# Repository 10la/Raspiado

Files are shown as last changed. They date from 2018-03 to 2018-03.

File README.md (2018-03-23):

## Raspiado

A USB hub that fits in the space and footprint of the existing Raspberry Pi.  Compatible with the RPi B, RPi B+, and RPi 2.

Power your Pi, add USB ports, and look great doing it!

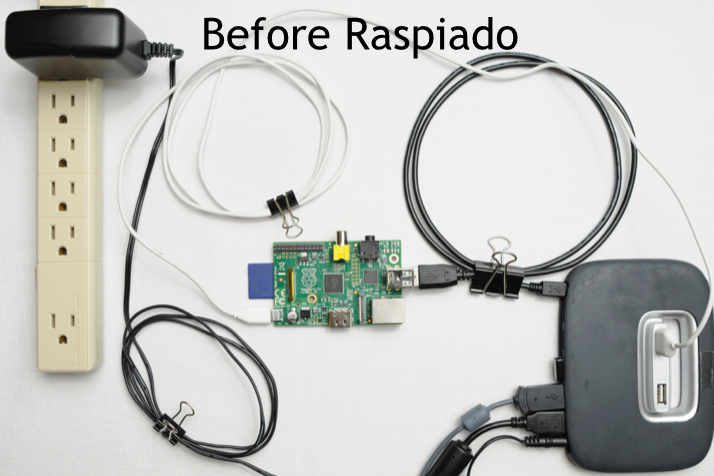
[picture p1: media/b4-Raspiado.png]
Before Rapiado


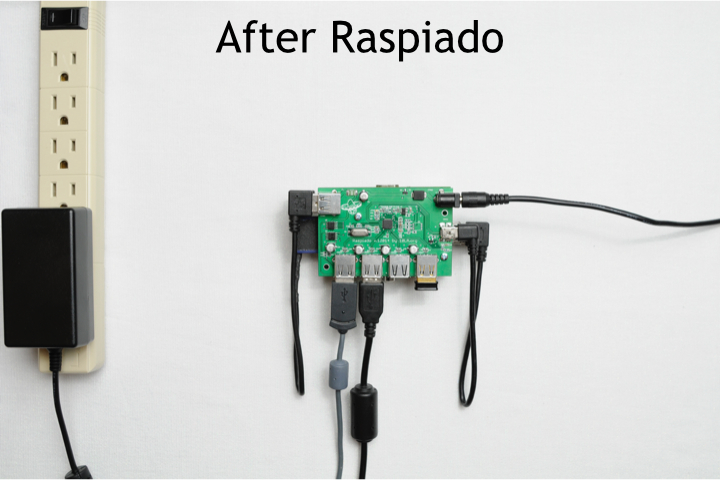
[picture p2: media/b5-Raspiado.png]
After Rapiado


******************
### File Descriptions
[4PxU_RPISB Specification.docx](https://github.com/10la/Raspiado/blob/master/4PxU_RPISB%20Specification.docx) is the hardware specification document created by Mindlab Tech for Raspiado.  It represents a formalized document that governs what functions and requirements Raspiado needed and how those things would be achieved.

[PCB Design Files](https://github.com/10la/Raspiado/tree/master/PCB%20Design%20Files) are the EAGLE files for the Raspiado board.

It includes 2 folders- the main design files are in [4PxU_RPi Rev B 18July2014](https://github.com/10la/Raspiado/tree/master/PCB%20Design%20Files/4PxU_RPi%20Rev%20B%2018July2014).  I had a small issue with the board logo and the resulting change are stored in [2014-10-3 new logo](https://github.com/10la/Raspiado/tree/master/PCB%20Design%20Files/2014-10-3%20new%20logo)

When I went to production with Raspiado, I required a few crossreferenced components in order to function with the inventory items that my PCB manufacturer preferred.  You can find those in the [BOM_Crossreferences](https://github.com/10la/Raspiado/blob/master/PCB%20Design%20Files/BOM_Raspiado_V1P4_crossreferences.xlsx) spreadsheet.

******************
### Kickstarter

Raspiado would have never seen the light of day with it's attractive, intelligent, and supportive backers.
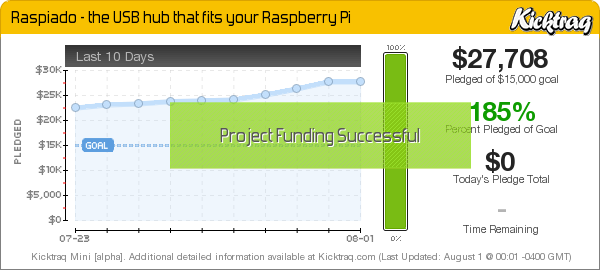
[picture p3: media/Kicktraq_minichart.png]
Kicktraq Stats


When I started the project, I never knew that I'd be able to create something that would be appreciated by people all over the world.
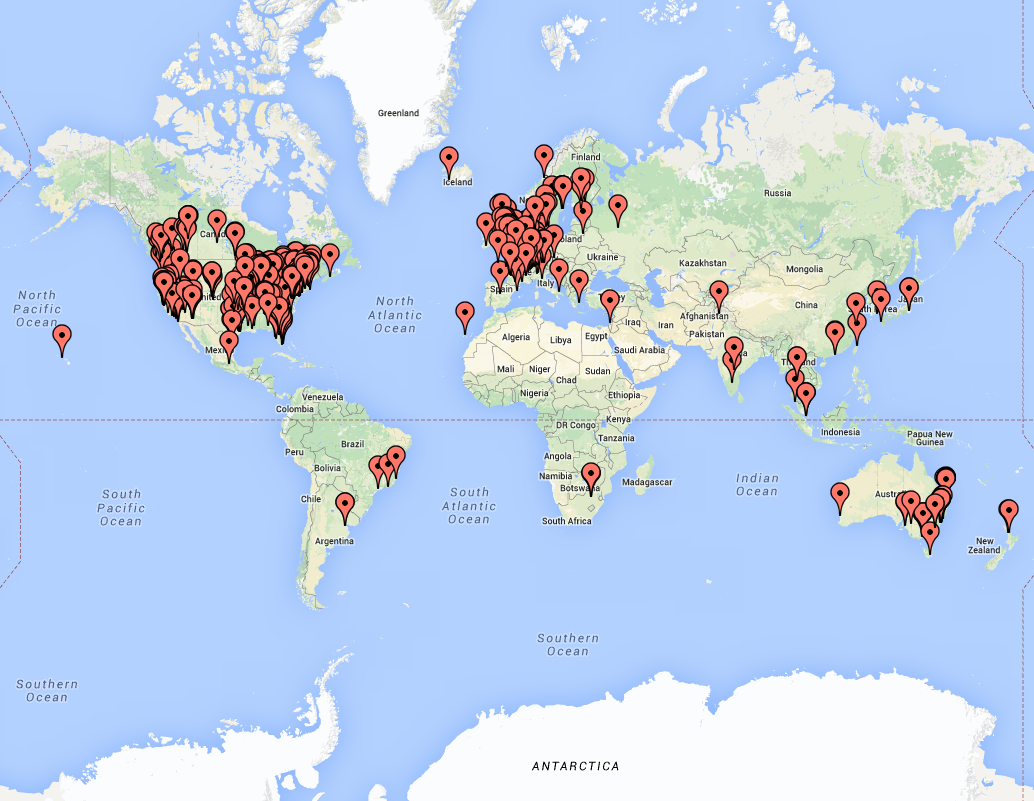
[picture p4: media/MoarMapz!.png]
Backer Map


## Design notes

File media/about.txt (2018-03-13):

RASPIADO
Besides being made up, raspiado essentially means "raspberried" and is the past participle of raspberry in Spanish.

To form the past participle in Spanish, simply drop the infinitive ending (-ar) and add -ado (for -ar verbs).

So, "to speak" is hablar in Spanish.

hablar - ar + ado = hablado

That translates to "spoken".

10 LETTER ACRONYM
In engineering there's an old, and somewhat bad, joke that goes

Old, haggard, and seasoned engineer - "there's a lot of TLA's in this business".

FNG - "What's a TLA?"

Old, haggard, and seasoned engineer - "three letter acronym"

CHRIS
I started 10 Letter Acronym to "scratch my own itch" relating to Raspberry Pi use.  I built a card eating robot for my wedding reception and was always dissapointed with the pile of cables I needed to get an otherwise tiny computer running.  I wanted a way to put everything, including the USB hub, into the space of the RPi.

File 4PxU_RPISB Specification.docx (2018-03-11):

4PxU_ RPISB

HW Specifications

4 Port USB Hub Raspberry Pi Stacking Board

Revision 0.3

Designer: Joseph John Bayalas

Email: jbayalas@mindlabtech.com

Revision History:

Revision No. | Description | Date | Author
0.1 | First draft. | | Jbayalas
0.2 | Added 3D drawings | 02/04/2014 | Jbayalas
0.3 | Added PCB snap shot Updated the PCB stack-up section. | 02/16/2014 | Jbayalas

# 1 Project/Design Details:

Customer | Chris
Project Name | 4 Port USB Hub Raspberry Pi Stacking Board
Design Code/Name | 4PxU_RPISB
Author | Joseph Bayalas
Date | February 2, 2014

# 2 Introduction

4PxU_RPISB is a stackable USB 2.0 hub that fits on the bottom of a revision B RaspberryPi (Rpi). The stacking board will provide adequate current capacity to power up RPi. The board will be stacked with Rpi’s bottom side.

The product will be the solution for the scarcity of USB hubs that is able to provide adequate power and mechanicaly work well with the small form factor of RPi.

This document will serve as product requirement and hardware specification document. This will also serve as guide for the Hardware, Layout, Mechanical and Manufacturing Engineers on how the product will be implemented.

The product will be prototype in Philippines and eventually manufacturing will be moved to US.

# 3 Product Requirements

Requirements | Descriptions | Comments
Req. 1 | RPi 5V Power Outlet (USB Type A Receptacle) | To be reviewed by the customer.
Req. 2 | RPi upstream port (USB Mini B Receptacle) | To be reviewed by the customer.
Req. 3 | 4 Port Type A Receptacle | To be reviewed by the customer.
Req. 4 | Req. 1 should be mechanically aligned to RPi S1 connector.
Req. 5 | Req. 2 should be mechanically aligned to RPi S7 connector.
Req. 6 | External 5V DC power supply connector (5.5mm x 2.1mm Barrel Jack) | To be reviewed by the customer.
Req. 7 | Board Outline should match RPi rev B including mounting holes.
Req. 8 | Overall height must be minimized. | To be reviewed by the customer.
Req. 9 | Board shall be mounted underneath RPi. | To be reviewed by the customer.
Req. 10 | Manufacturing will be moved to US.
Req. 11 | Eagle files and libraries must be provided.
Req. 12 | Prototypes will be provided.

# 4 Sytems Overview

The block diagram shows the interconnection between the RPi and the stacking board.

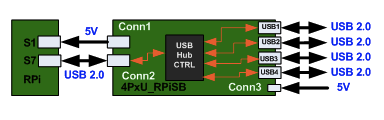
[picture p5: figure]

# 5 Hardware Implementation

## 5.1 5V Power Outlet Connector

S1 of RPi will be connected to Conn 1 of the stacking board. Conn 1 of the stacking board serves as a 5V power outlet to supply power on the RPi and its peripherals. This connector will be implemented with a USB Type A receptacle.

A 2A Fuse will be added to this port for safety precautions. RPi should only draw maximum of 1.5A on this port.

## 5.2 Uptream USB 2.0 Port

One of the USB port of the 2x USB(S7) connector will be connected to the uptream port (Conn 2) of the stacking board. This connector will be implemeted using a USB mini B receptacle.

## 5.3 Downsteam USB 2.0 Ports

There will be 4 USB 2.0 Ports.

Each of the ports will have the ff:

a.) EMI Filters for the 5V Vbus line
b.) EMI Filter for the USB lines
c.) ESD protection Diodes
d.) Current Limiter on 5V Vbus line
e.) Port Power Status LED

## 5.4 5V Power Inlet Connector

This is where the external power supply will be connected. The connector will use a 5mm x 2.1mm barrel jack. A low voltage drop diode will be connected to the positive line of the jack to protect from accidental polarity reversal by the user. Voltage clamp will also be provided for over voltage protection.

### 5.4.1 Power Distribution

The external power supply must be a 4A, 5V power supply. The power supply is from TBD supplier.

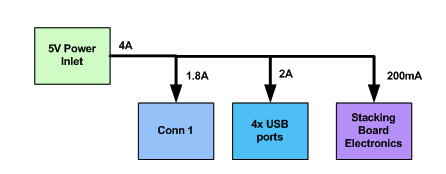
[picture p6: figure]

Here’s the power budget:

Component | Consumption (A) | Description
Conn 1 | 1.8 | 5V Power Outlet
USB1 | 0.5 | USB port 1
USB2 | 0.5 | USB port 2
USB3 | 0.5 | USB port 3
USB4 | 0.5 | USB port 4
Stacking board | 0.2 | Consumption for the stacking board connector.
Total | 4 | A

## 5.5 USB Hub Controller

The USB Hub controller chip that will be used is USB2514BQFN36 from SMSC.

Details will be provided later…

# 6 Physical Implementation

## 6.1 PCB Stackup

The PCB will be a 2 layer board.

Top → 1 oz

Prepreg → 31 mils

Bottom → 1 oz

## 6.2 Board Outline

Top:

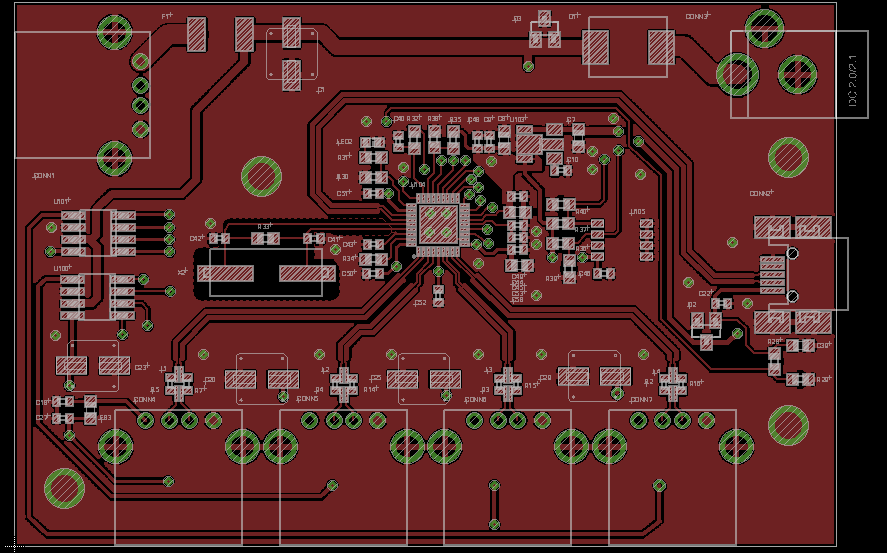
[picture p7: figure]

Bottom:

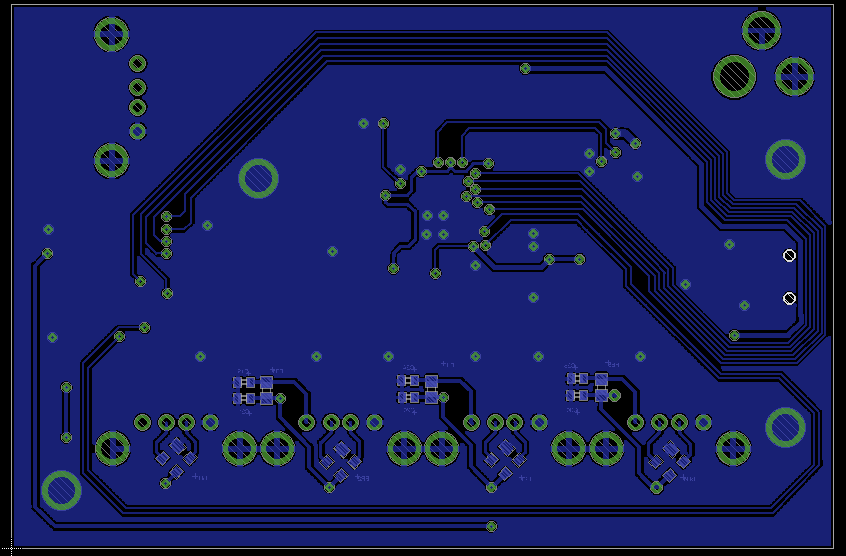
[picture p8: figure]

## 6.3 Component Placement

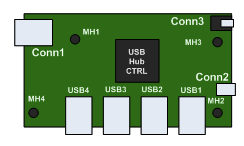
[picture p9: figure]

MH1 and MH2 is for RPi stacking.

MH3 and MH4 is for user applications.

Top View:

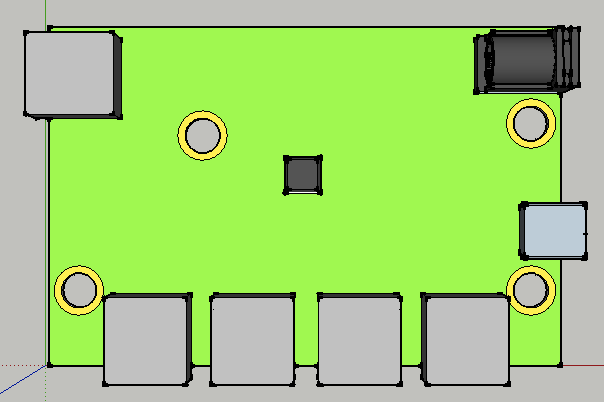
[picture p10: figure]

Bottom View:

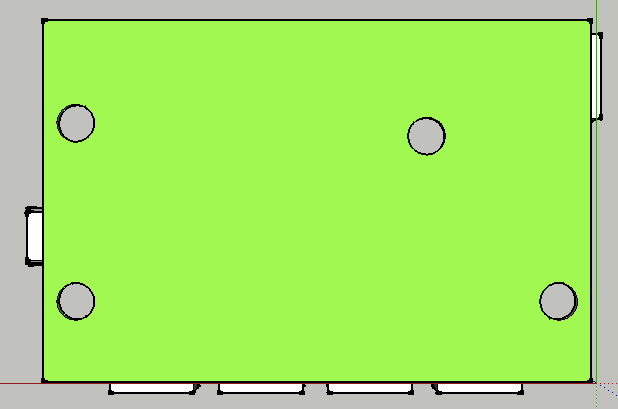
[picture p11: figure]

Front View:

Back View:

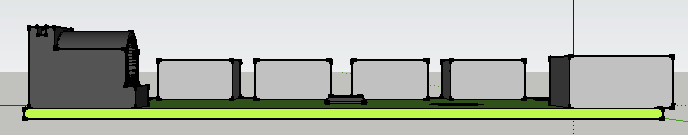
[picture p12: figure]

Left View:

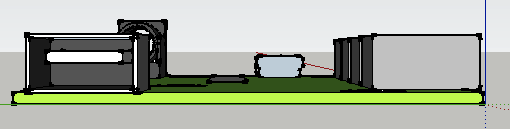
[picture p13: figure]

Right View:

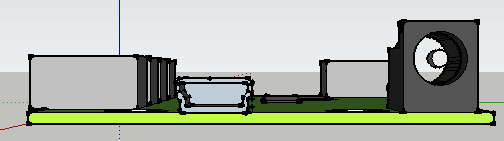
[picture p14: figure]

Isometric View:

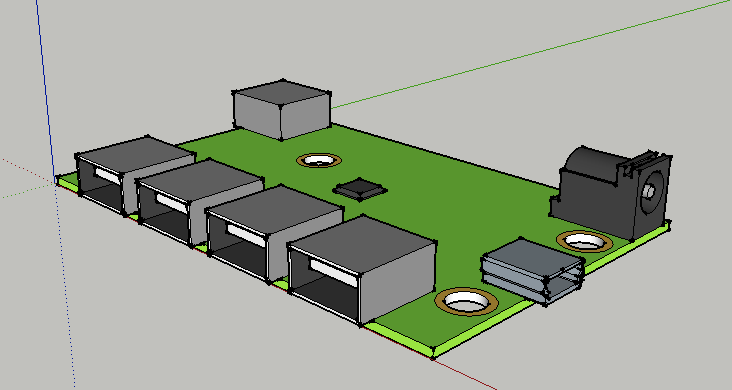
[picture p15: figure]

## 6.4 Stacking Profile

Top View:

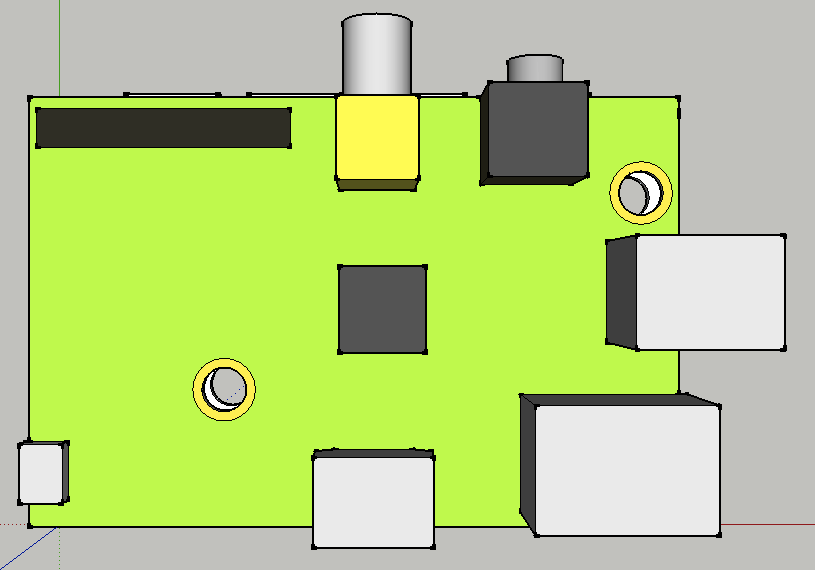
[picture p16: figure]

Bottom View:

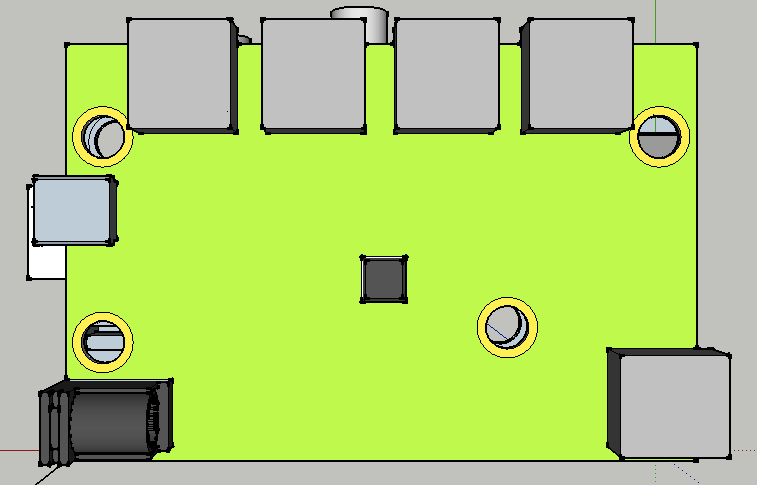
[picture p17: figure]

Front View:

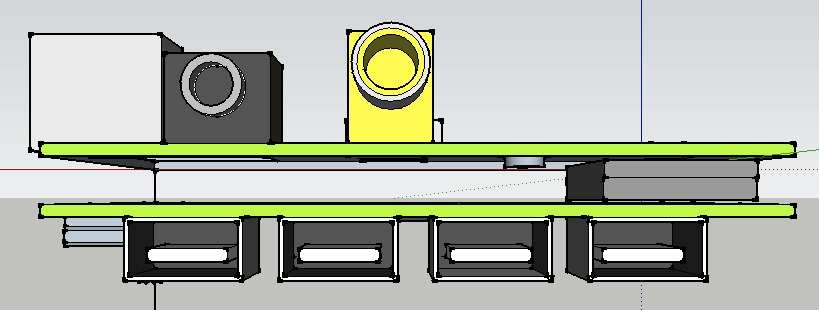
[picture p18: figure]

Back View:

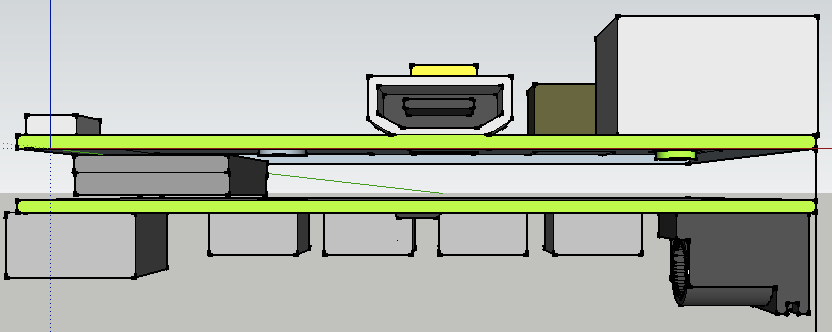
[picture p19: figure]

Left View:

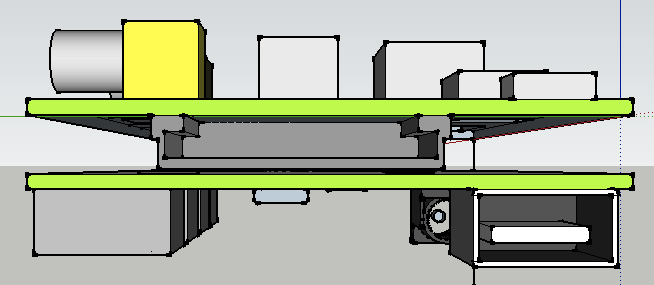
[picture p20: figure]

Right View:

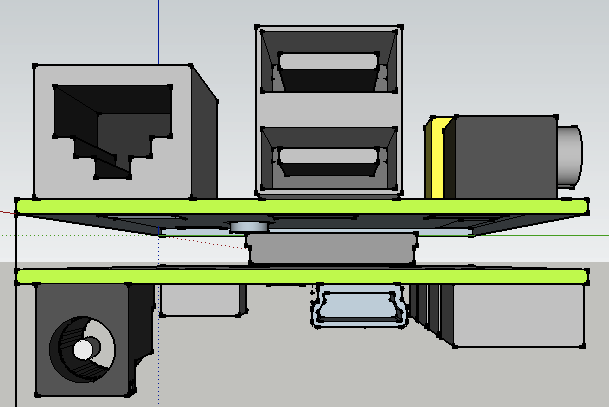
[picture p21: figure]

Isometric View:

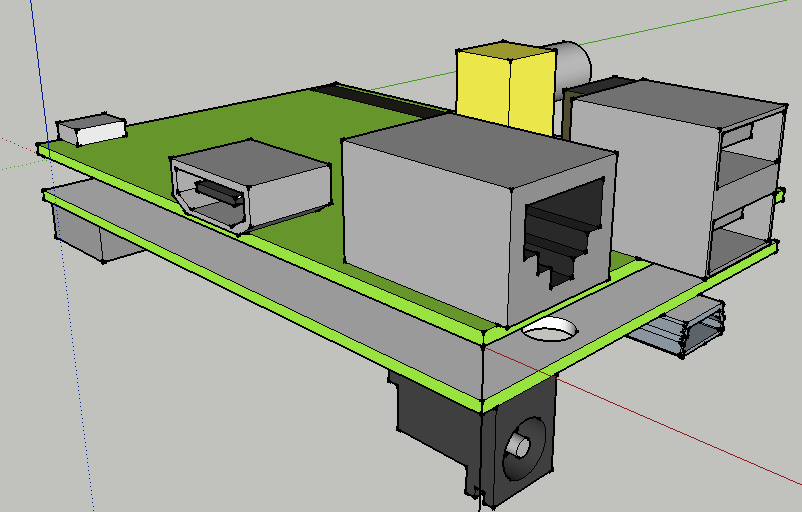
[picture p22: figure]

## 6.5 PCB markings

TBD

17 February 20142 | Page .com

4PxU_RPISB HWS Advanced Mindlab Technologies Inc. R&D Forms and Standards

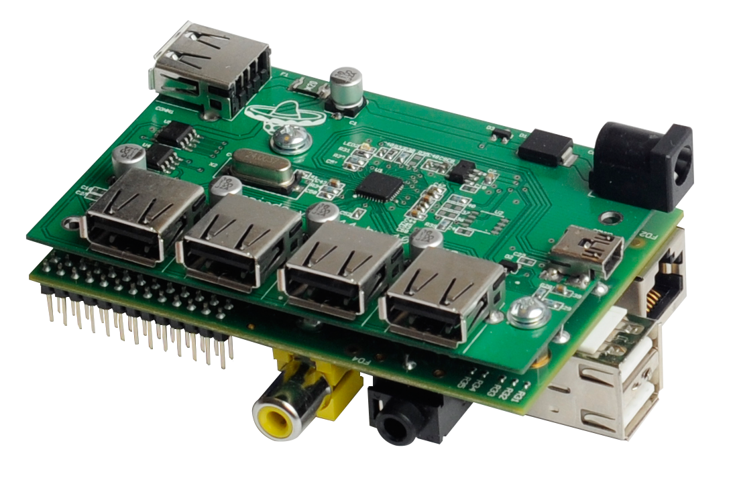
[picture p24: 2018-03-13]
media/Quartering.png

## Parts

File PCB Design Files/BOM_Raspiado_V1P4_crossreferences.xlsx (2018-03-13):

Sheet: Revision History
Revision | Description | Designer | Release Date
1.1 | Changed barrel jack from 3.5A rating to a 5A rated part. | Jbayalas | 2014-04-05
1.2 | Added C50 0.1uF capacitor in the BOM | Lbalucos | 2014-04-08
1.2 | 1.0nF capacitor package changed from 0603 to 0402 | Lbalucos | 2014-04-08
1.3 | UMK107SD102JA-T capacitor replaced with C1005C0G1H102K050BA | Lbalucos | 2014-05-28
1.3 | 675031030 connector replaced with 67503-1020 | Lbalucos | 2014-05-28
1.3 | DLP11SN900SL2 inductor replaced with DLP11SN900SL2L | Lbalucos | 2014-05-28
1.3 | PJ-002AH led replaced with C1005C0G1H102K050BA | Lbalucos | 2014-05-28
1.3 | PQ1L333M2SP ic regulator replaced with NCP694H33HT1G | Lbalucos | 2014-05-28
1.4 | KLDHCX-0202-AC barrel jack replaced with PJ-058AH | Lbalucos | 2014-06-23
1.4 | "Raspiado v.12014 by 10LA.org" text changed to "Raspiado v.A by 10LA.org" | Lbalucos | 2014-06-23

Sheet: Raspiado BOM
 |  |  | Project: | Raspiado
 |  |  | Document: | BILL OF MATERIALS (BOM)
 |  |  | Revision: | V1.4
 |  |  | Prepared By: | Jbayalas@mindlabtech.com
 |  |  | Release Date: | 2014-06-23
www.mindlabtech.com
ITEM # | REF DES | CH | VALUE | DESCRIPTION | QTY | MANUFACTURER | MFG. PART # | PACKAGE | TYPE | LOAD OPTIONS | Alt Mfg | Alt Part # | Website
1 | BR1,BR2,BR3,BR4 |  | BGX50A | Diode, Bridge, Switching, 50v, 140mA, KCAC, SOT-143 | 4 | Infineon Tech | BGX50A | SOT143 | SMD | DNP
2 | C1,C20,C23,C25,C29 | X | 100uF | Capacitor, Low ESR, 100uF, 6.3VDC, 20%, Aluminum, Radial-SMT, 5mm x 5.8mm | 5 | United Chemi-Con | EMZA6R3ADA101ME61G | Radial SMT | SMD |  | Panasonic | EEE-FK0J101UR | http://www.mouser.com/ProductDetail/Panasonic/EEE-FK0J101UR/
3 | C7,C39,43,C44,C58 | X | 1.0uF | Capacitor, 1.0uF, 10%, 6.3V, X5R, 0603 | 5 | Murata | GRM155R60J105KE19D | 0603 | SMD
4 | C8,C49 | X | 4.7uF | Capacitor, 4.7uF, 6.3VDC, 20%, X5R, 0603 | 2 | Murata | GRM188R60J475KE19D | 0603 | SMD
5 | C9,C10,C18,C19,C22,C24,C28 | X | 1.0nF | Capacitor,Multilayer Ceramic Capacitors MLCC - SMD/SMT | 7 | TDK | C1005C0G1H102K050BA | 0402 | SMD |  | Yageo/ Phycomp | CC0402KRX7R9BB102
6 | C21,C26,C27,C30,C40,C45,C47,C48,C50,C51,C52,C53 | X | 0.1uF | Capacitor, 0.1uF, 6.3V, 10%, X5R, 0402 | 12 | Murata | GRM155R71A104KA01D | 0402 | SMD
7 | C46 | X | 0.1uF | Capacitor, 0.1uF, 6.3V, 10%, X5R, 0402 | 1 | Murata | GRM155R71A104KA01D | 0402 | SMD | DNP
8 | C41,C42 | X | 18pF | Capacitor, 18pF, 50V, 5%, NPO, 0402 | 2 | Murata | GRM1555C1H180JZ01 | 0402 | SMD |  | murata | GRM1555C1H180JA01D | http://www.mouser.com/ProductDetail/Murata-Electronics/GRM1555C1H180JA01D/
9 | CONN1,CONN4,CONN5,CONN6,CONN7 | X | 292303-1 | Connector, USB, Style A, Right Angle, Through-hole | 5 | AMP | 292303-1 | Style A, Right Angle, Through-hole | THRU hole
10 | CONN2 | X | 67503-1020 | Connector,USB Connectors USB Mini-B Recept On-The-Go Rt.Angle | 1 | Molex (http://sg.mouser.com/molex/) | 67503-1020 | MINI-B | SMD
11 | CONN3 | X | PJ-058AH | Connector, DC Barrel Jack,2mm Pin diameter | 1 | CUI Inc | KLDHCX-0202-AC | 2mm pitch thru hole | THRU hole
12 | D1 | X | B520C | Diode, 5.0A SURFACE MOUNT SCHOTTKY BARRIER RECTIFIER | 1 | Diodes | B520C | SMC | SMD |  | Diodes | B520C-13-F | http://www.mouser.com/ProductDetail/Diodes-Incorporated/B520C-13-F/?qs=sGAEpiMZZMs24GWi4QakPwy1avpqXjp6
13 | D2 | X | PMEG4005ET | Diode ,0.5 A,MEGA Schottky barrier rectifiers,SOT23 | 1 | NXP | PMEG4005ET | SOT23 | SMD |  | NXP semiconductors | PMEG4005ET215 (https://circuithub.com/parts-new/NXP/PMEG4005ET215)
14 | D3 | X | MMBZ5V6ALT1G | Diode, TVS, Arrays 5.6V 225mW Dual Common Anode | 1 | On Semiconductor | MMBZ5V6ALT1G | SOT23 | SMD
15 | F1 | X | MINI-SMDC200F | Fuse, PPTC 2A 8V 100A | 1 | Tyco electronics | MINI-SMDC200F | MINI-SMDC200F | SMD
16 | FB3,FB4,FB5,FB6 | X | BLM18EG221SN1D | Ferrite Bead, 220 Ohm, 2A, 0.05DCR, 0603 | 4 | Murata | BLM18EG221SN1D | C0603 | SMD
17 | L1,L2,L3,L4 | X | DLP11SN900SL2L | Inductor,Common Mode Filters / Chokes 0504 90ohm EMI Suppression Fltr | 4 | Murata | DLP11SN900SL2L | 0504 | SMD | DNP
18 | LED2 | X | VLMTG1300-GS08 | LED,Standard LEDs - SMD True Green Clear Non-Diff | 1 | Vishay Semiconductors (http://sg.mouser.com/vishaysemiconductors/) | VLMTG1300-GS08 | 0603 | SMD | DNP
19 | R2,R3,R4,R5,R7,R14,R15,R16 | X | 0Ω | Resistor, 0ohm,0402 | 8 | KOA Speer electronics | RK73Z1ETTP | 0402 | SMD
20 | R28,R29,R30,R38,R39,R40 | X | 100K | Resistor, 100K, 5%, 1/16W, 0603 | 6 | Panasonic | ERJ-3GEYJ104V | 0603 | SMD
21 | R31 | X | 1K | Resistor, 1K, 5%, 1/16W, 0603 | 1 | Panasonic | ERJ-3GEYJ102V | 0603 | SMD | DNP
22 | R32 | X | 1K | Resistor, 1K, 5%, 1/16W, 0603 | 1 | Panasonic | ERJ-3GEYJ102V | 0603 | SMD
23 | R33 | X | 1M | Resistor, 1Meg, 5%, 1/16W, 0603 | 1 | Panasonic | ERJ-3GEYJ105V | 0603 | SMD
24 | R34 | X | 12.0K | Resistor, 12.0K, 1%, 1/16W, 0603 | 1 | Panasonic | ERJ-3EKF1202V | 0603 | SMD
25 | R35,R36,R37 | X | 10K | Resistor, 10.0K, 1%, 1/16W, 0603 | 3 | Panasonic | RK73H1JTTD1002F | 0603 | SMD | DNP
26 | U1 | X | USB2514USB2514B-AEZG | IC, USB2514B, 4 Port USB 2.0 Hub, QFN36 | 1 | SMSC | USB2514B-AEZG | QFN36 | SMD
27 | U2 | X | 24C04 | IC, EEPROM,3V to 5.5V for ST24x04, | 1 | ST | 24C04 | SO-8 | SMD | DNP
28 | U3 | X | NCP694H33HT1G | IC,LDO Voltage Regulators 1A CMOS B/S LDO | 1 | On Semiconductor | NCP694H33HT1G | SOT-89 | SMD
29 | U4, U5 | X | MIC2026A-1YM | IC, MIC2026A-1YM, Power Distribution Switch, SO-8 | 2 | Micrel | MIC2026-1YM | SO-8 | SMD
30 | X2 | X | 24.000MHz | Crystal, 24.000MHz, 50ppm, 18pF, HC-49SMT | 1 | Citizen America | HCM49-24.000MABJ-UT | HC-49SMT | SMD |  |  |  | http://www.mouser.com/ProductDetail/ECS/ECS-240-18-5PXEN-TR/
 |  |  |  | Total | 85

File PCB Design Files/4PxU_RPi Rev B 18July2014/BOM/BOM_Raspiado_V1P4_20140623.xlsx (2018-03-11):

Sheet: Revision History
Revision | Description | Designer | Release Date
1.1 | Changed barrel jack from 3.5A rating to a 5A rated part. | Jbayalas | 2014-04-05
1.2 | Added C50 0.1uF capacitor in the BOM | Lbalucos | 2014-04-08
1.2 | 1.0nF capacitor package changed from 0603 to 0402 | Lbalucos | 2014-04-08
1.3 | UMK107SD102JA-T capacitor replaced with C1005C0G1H102K050BA | Lbalucos | 2014-05-28
1.3 | 675031030 connector replaced with 67503-1020 | Lbalucos | 2014-05-28
1.3 | DLP11SN900SL2 inductor replaced with DLP11SN900SL2L | Lbalucos | 2014-05-28
1.3 | PJ-002AH led replaced with C1005C0G1H102K050BA | Lbalucos | 2014-05-28
1.3 | PQ1L333M2SP ic regulator replaced with NCP694H33HT1G | Lbalucos | 2014-05-28
1.4 | KLDHCX-0202-AC barrel jack replaced with PJ-058AH | Lbalucos | 2014-06-23
1.4 | "Raspiado v.12014 by 10LA.org" text changed to "Raspiado v.A by 10LA.org" | Lbalucos | 2014-06-23

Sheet: Raspiado BOM
 |  | Project: | Raspiado
 |  | Document: | BILL OF MATERIALS (BOM)
 |  | Revision: | V1.4
 |  | Prepared By: | Jbayalas@mindlabtech.com
 |  | Release Date: | 2014-06-23
www.mindlabtech.com
ITEM # | REF DES | VALUE | DESCRIPTION | QTY | MANUFACTURER | MFG. PART # | PACKAGE | TYPE | LOAD OPTIONS
1 | BR1,BR2,BR3,BR4 | BGX50A | Diode, Bridge, Switching, 50v, 140mA, KCAC, SOT-143 | 4 | Infineon Tech | BGX50A | SOT143 | SMD | DNP
2 | C1,C20,C23,C25,C29 | 100uF | Capacitor, Low ESR, 100uF, 6.3VDC, 20%, Aluminum, Radial-SMT, 5mm x 5.8mm | 5 | United Chemi-Con | EMZA6R3ADA101ME61G | Radial SMT | SMD
3 | C7,C39,43,C44,C58 | 1.0uF | Capacitor, 1.0uF, 10%, 6.3V, X5R, 0603 | 5 | Murata | GRM155R60J105KE19D | 0603 | SMD
4 | C8,C49 | 4.7uF | Capacitor, 4.7uF, 6.3VDC, 20%, X5R, 0603 | 2 | Murata | GRM188R60J475KE19D | 0603 | SMD
5 | C9,C10,C18,C19,C22,C24,C28 | 1.0nF | Capacitor,Multilayer Ceramic Capacitors MLCC - SMD/SMT | 7 | TDK | C1005C0G1H102K050BA | 0402 | SMD
6 | C21,C26,C27,C30,C40,C45,C47,C48,C50,C51,C52,C53 | 0.1uF | Capacitor, 0.1uF, 6.3V, 10%, X5R, 0402 | 12 | Murata | GRM155R71A104KA01D | 0402 | SMD
7 | C46 | 0.1uF | Capacitor, 0.1uF, 6.3V, 10%, X5R, 0402 | 1 | Murata | GRM155R71A104KA01D | 0402 | SMD | DNP
8 | C41,C42 | 18pF | Capacitor, 18pF, 50V, 5%, NPO, 0402 | 2 | Murata | GRM1555C1H180JZ01 | 0402 | SMD
9 | CONN1,CONN4,CONN5,CONN6,CONN7 | 292303-1 | Connector, USB, Style A, Right Angle, Through-hole | 5 | AMP | 292303-1 | Style A, Right Angle, Through-hole | THRU hole
10 | CONN2 | 67503-1020 | Connector,USB Connectors USB Mini-B Recept On-The-Go Rt.Angle | 1 | Molex (http://sg.mouser.com/molex/) | 67503-1020 | MINI-B | SMD
11 | CONN3 | PJ-058AH | Connector, DC Barrel Jack,2mm Pin diameter | 1 | CUI Inc | KLDHCX-0202-AC | 2mm pitch thru hole | THRU hole
12 | D1 | B520C | Diode, 5.0A SURFACE MOUNT SCHOTTKY BARRIER RECTIFIER | 1 | Diodes | B520C | SMC | SMD
13 | D2 | PMEG4005ET | Diode ,0.5 A,MEGA Schottky barrier rectifiers,SOT23 | 1 | NXP | PMEG4005ET | SOT23 | SMD
14 | D3 | MMBZ5V6ALT1G | Diode, TVS, Arrays 5.6V 225mW Dual Common Anode | 1 | On Semiconductor | MMBZ5V6ALT1G | SOT23 | SMD
15 | F1 | MINI-SMDC200F | Fuse, PPTC 2A 8V 100A | 1 | Tyco electronics | MINI-SMDC200F | MINI-SMDC200F | SMD
16 | FB3,FB4,FB5,FB6 | BLM18EG221SN1D | Ferrite Bead, 220 Ohm, 2A, 0.05DCR, 0603 | 4 | Murata | BLM18EG221SN1D | C0603 | SMD
17 | L1,L2,L3,L4 | DLP11SN900SL2L | Inductor,Common Mode Filters / Chokes 0504 90ohm EMI Suppression Fltr | 4 | Murata | DLP11SN900SL2L | 0504 | SMD | DNP
18 | LED2 | VLMTG1300-GS08 | LED,Standard LEDs - SMD True Green Clear Non-Diff | 1 | Vishay Semiconductors (http://sg.mouser.com/vishaysemiconductors/) | VLMTG1300-GS08 | 0603 | SMD | DNP
19 | R2,R3,R4,R5,R7,R14,R15,R16 | 0Ω | Resistor, 0ohm,0402 | 8 | KOA Speer electronics | RK73Z1ETTP | 0402 | SMD
20 | R28,R29,R30,R38,R39,R40 | 100K | Resistor, 100K, 5%, 1/16W, 0603 | 6 | Panasonic | ERJ-3GEYJ104V | 0603 | SMD
21 | R31 | 1K | Resistor, 1K, 5%, 1/16W, 0603 | 1 | Panasonic | ERJ-3GEYJ102V | 0603 | SMD | DNP
22 | R32 | 1K | Resistor, 1K, 5%, 1/16W, 0603 | 1 | Panasonic | ERJ-3GEYJ102V | 0603 | SMD
23 | R33 | 1M | Resistor, 1Meg, 5%, 1/16W, 0603 | 1 | Panasonic | ERJ-3GEYJ105V | 0603 | SMD
24 | R34 | 12.0K | Resistor, 12.0K, 1%, 1/16W, 0603 | 1 | Panasonic | ERJ-3EKF1202V | 0603 | SMD
25 | R35,R36,R37 | 10K | Resistor, 10.0K, 1%, 1/16W, 0603 | 3 | Panasonic | RK73H1JTTD1002F | 0603 | SMD | DNP
26 | U1 | USB2514USB2514B-AEZG | IC, USB2514B, 4 Port USB 2.0 Hub, QFN36 | 1 | SMSC | USB2514B-AEZG | QFN36 | SMD
27 | U2 | 24C04 | IC, EEPROM,3V to 5.5V for ST24x04, | 1 | ST | 24C04 | SO-8 | SMD | DNP
28 | U3 | NCP694H33HT1G | IC,LDO Voltage Regulators 1A CMOS B/S LDO | 1 | On Semiconductor | NCP694H33HT1G | SOT-89 | SMD
29 | U4, U5 | MIC2026A-1YM | IC, MIC2026A-1YM, Power Distribution Switch, SO-8 | 2 | Micrel | MIC2026-1YM | SO-8 | SMD
30 | X2 | 24.000MHz | Crystal, 24.000MHz, 50ppm, 18pF, HC-49SMT | 1 | Citizen America | HCM49-24.000MABJ-UT | HC-49SMT | SMD
 |  |  | Total | 85

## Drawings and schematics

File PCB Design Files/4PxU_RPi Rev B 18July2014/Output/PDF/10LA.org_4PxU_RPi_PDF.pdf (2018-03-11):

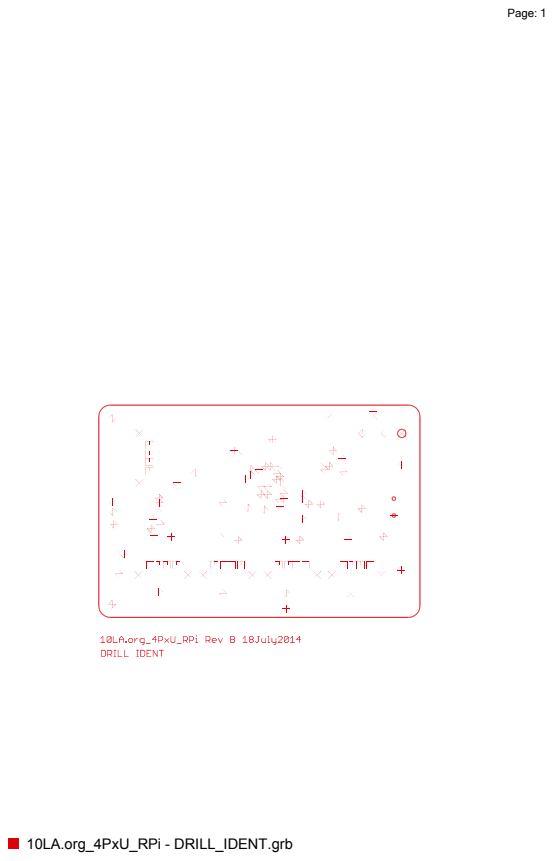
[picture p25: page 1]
10LA.org_4PxU_RPi - DRILL_IDENT.grb

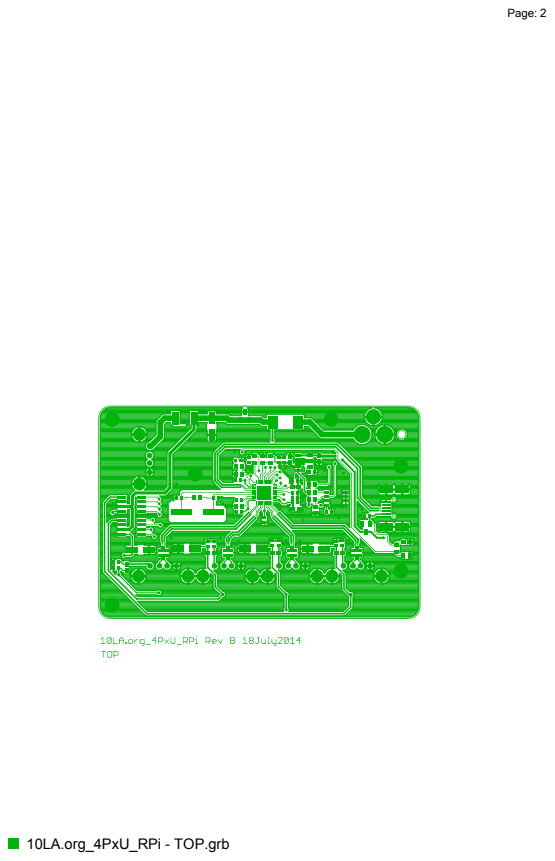
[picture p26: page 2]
10LA.org_4PxU_RPi - TOP.grb

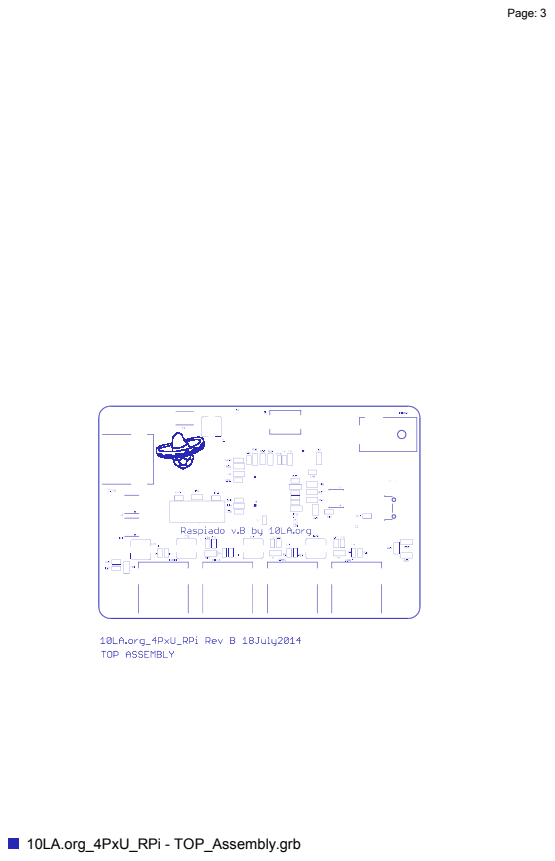
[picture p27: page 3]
10LA.org_4PxU_RPi - TOP_Assembly.grb

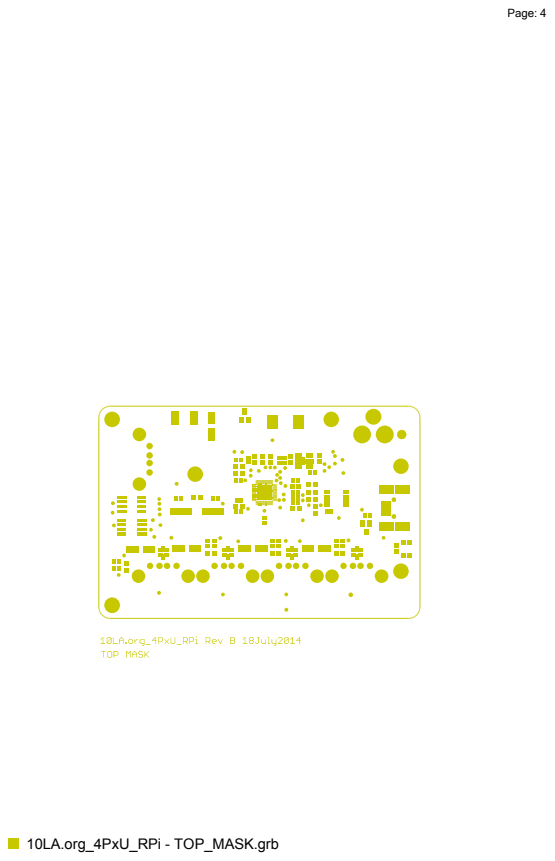
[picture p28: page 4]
10LA.org_4PxU_RPi - TOP_MASK.grb

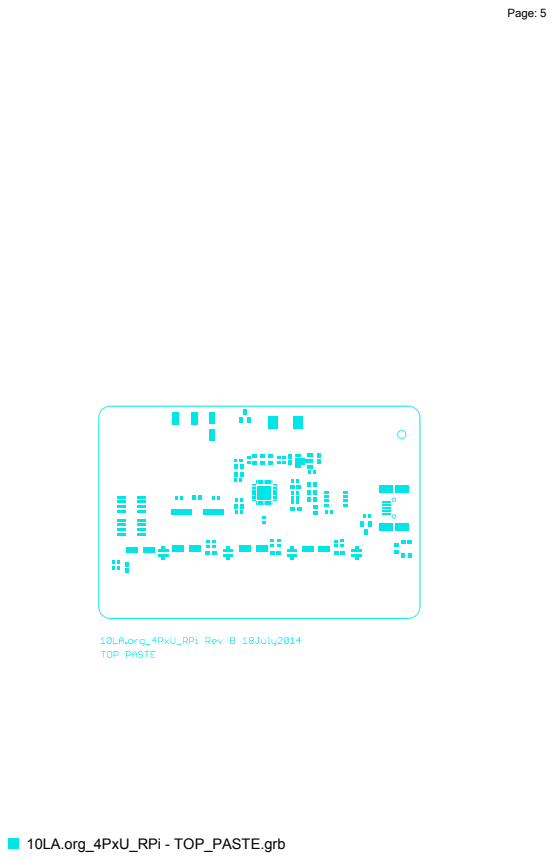
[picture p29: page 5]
10LA.org_4PxU_RPi - TOP_PASTE.grb

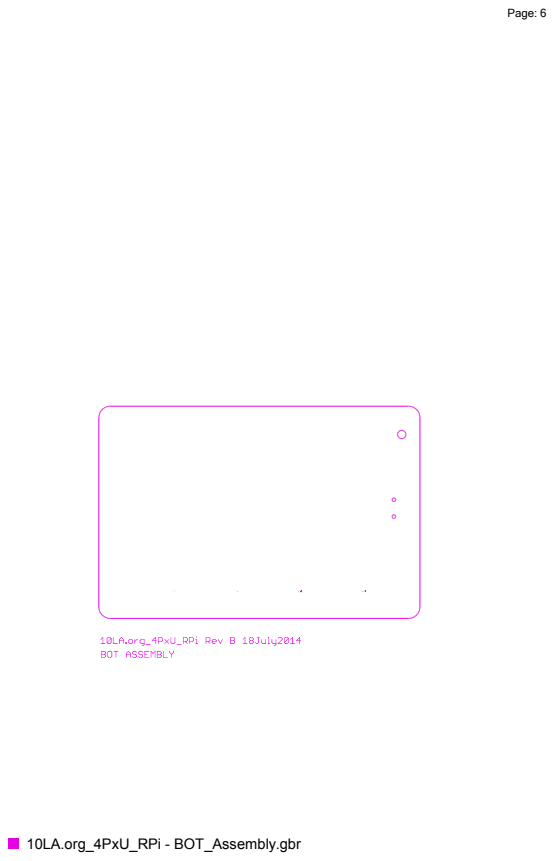
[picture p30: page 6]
10LA.org_4PxU_RPi - BOT_Assembly.gbr

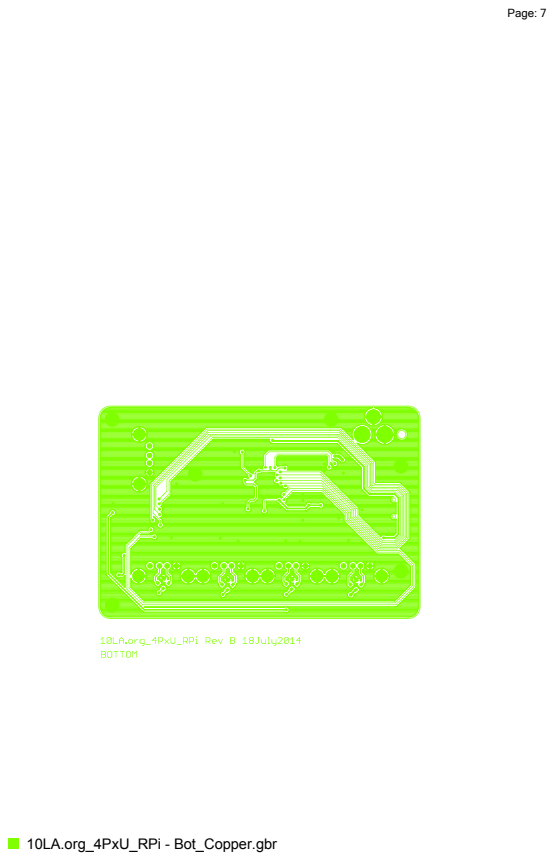
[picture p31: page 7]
10LA.org_4PxU_RPi - Bot_Copper.gbr

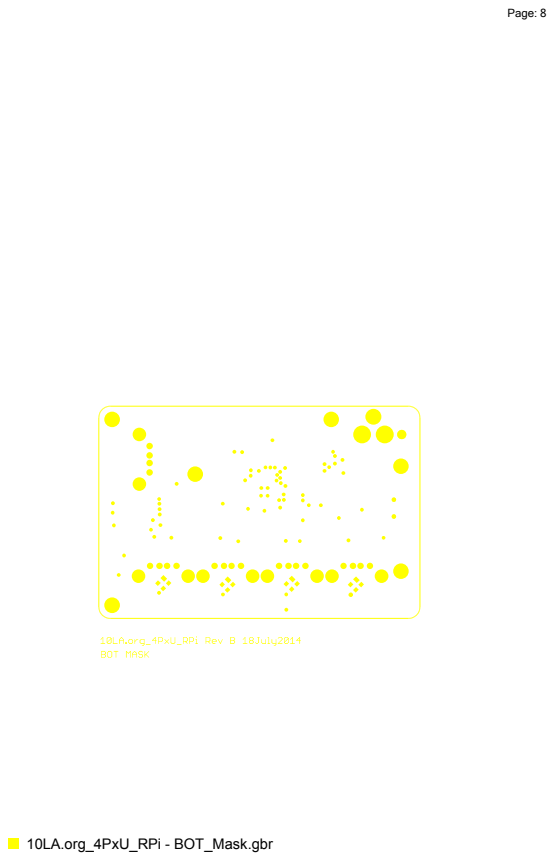
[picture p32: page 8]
10LA.org_4PxU_RPi - BOT_Mask.gbr

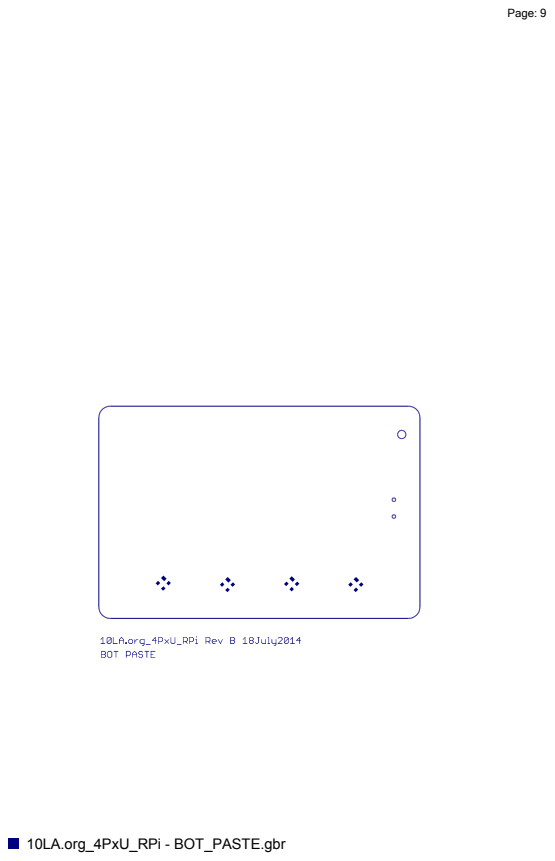
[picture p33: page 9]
10LA.org_4PxU_RPi - BOT_PASTE.gbr

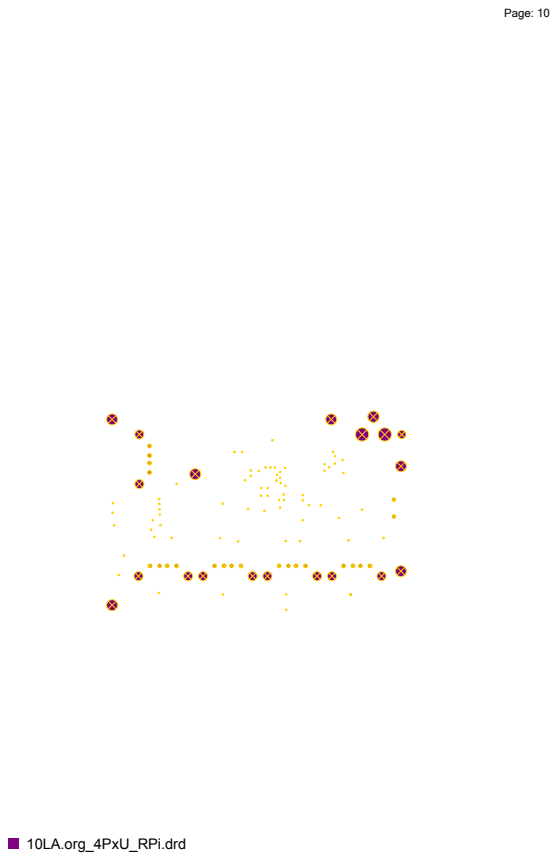
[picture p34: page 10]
10LA.org_4PxU_RPi.drd

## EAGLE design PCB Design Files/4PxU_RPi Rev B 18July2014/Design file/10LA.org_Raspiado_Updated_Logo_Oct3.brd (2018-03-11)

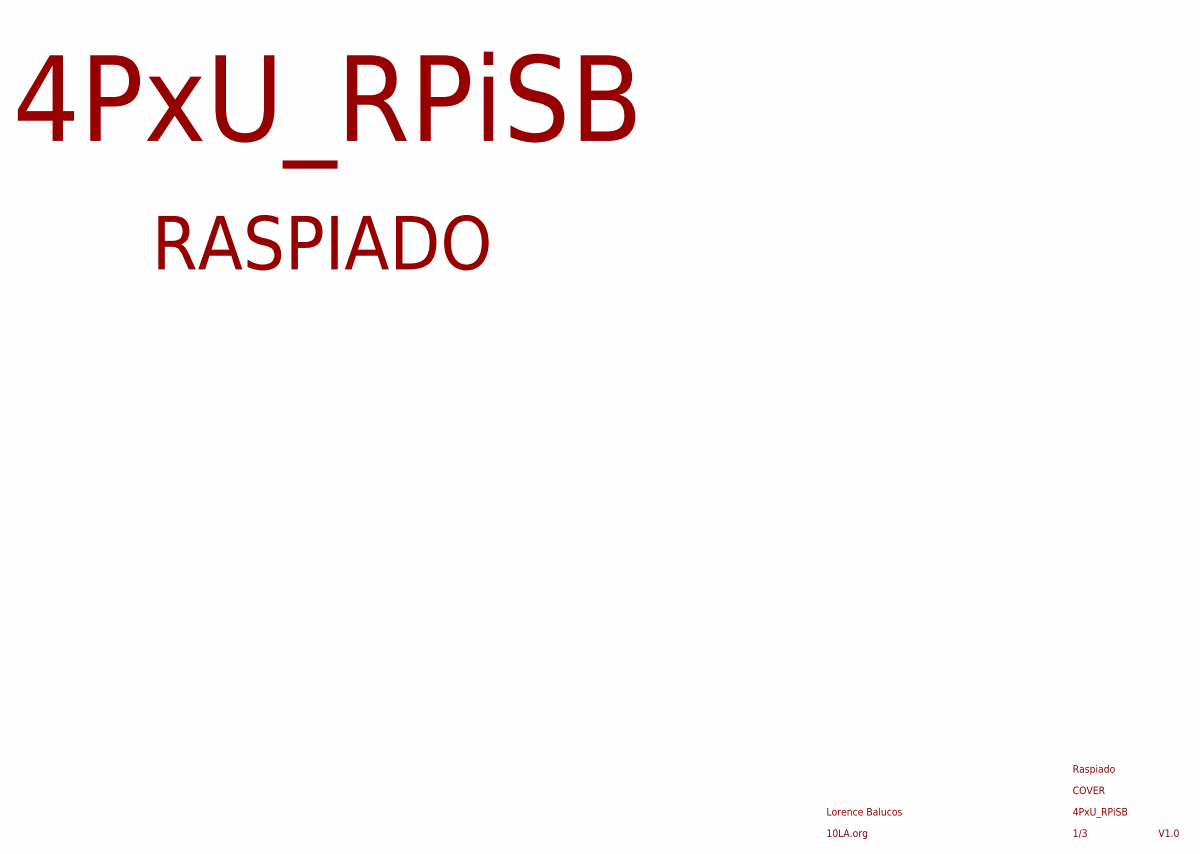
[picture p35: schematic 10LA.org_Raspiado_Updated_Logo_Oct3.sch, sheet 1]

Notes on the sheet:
1/3
4PxU_RPiSB
V1.0
10LA.org
RASPIADO
COVER
Lorence Balucos
Raspiado

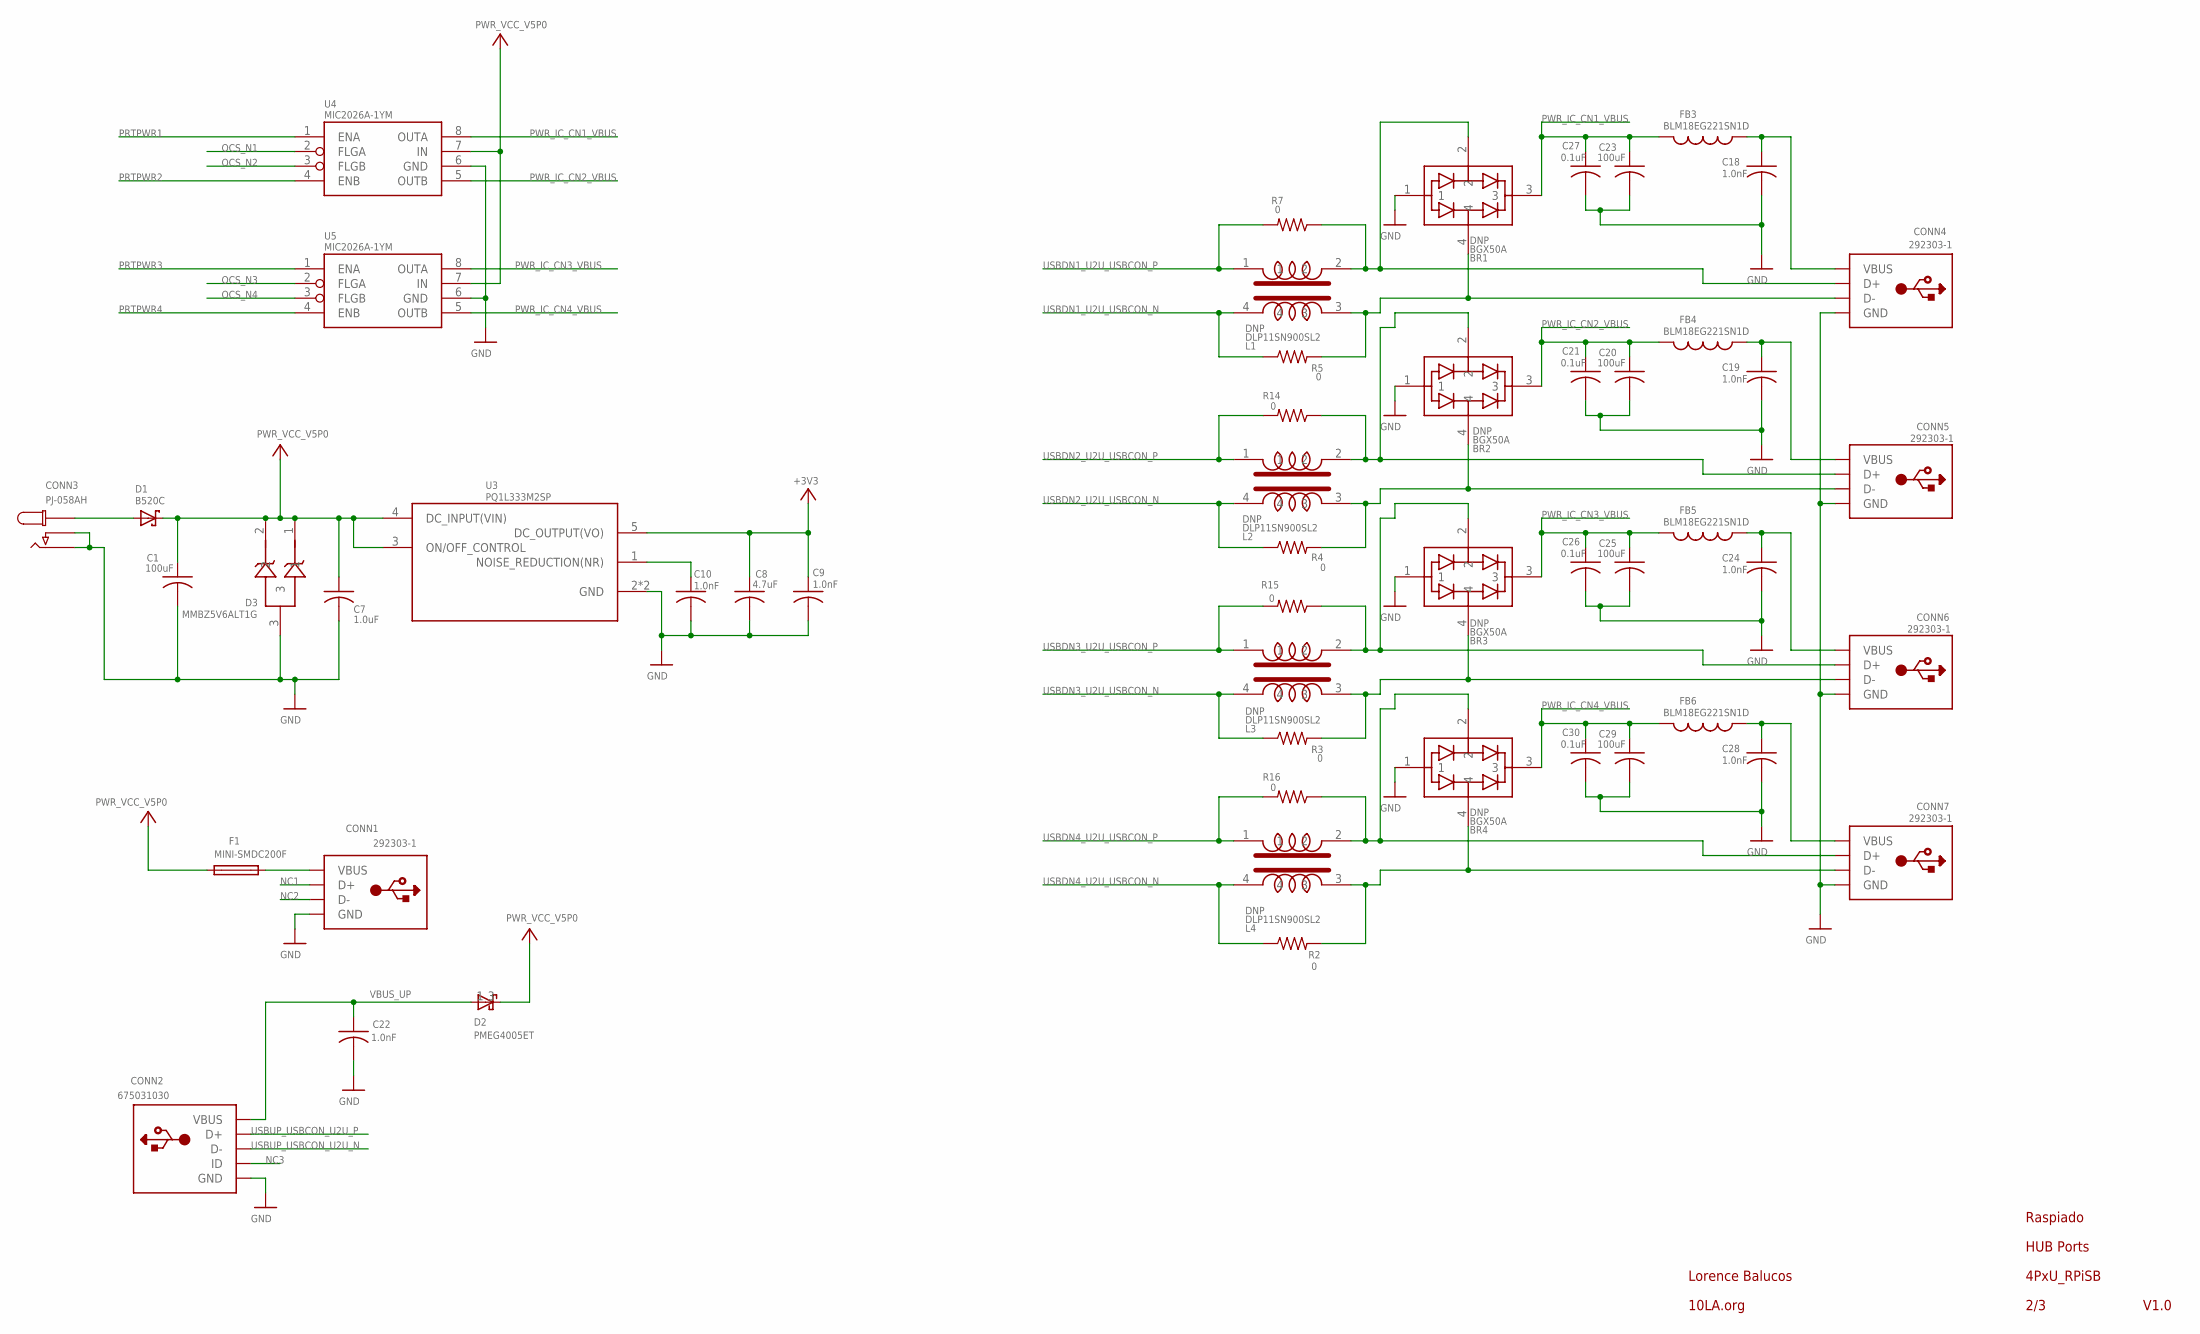
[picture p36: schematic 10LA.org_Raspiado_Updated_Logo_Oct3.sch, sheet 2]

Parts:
BR1, BR2, BR3, BR4: BGX50A; SOT-143
C1, C20, C23, C25, C29: 100uF; RADIAL_SMT
C7: 1.0uF; C0603
C8: 4.7uF; C0603
C9, C10, C18, C19, C22, C24, C28: 1.0nF; 0402
C21, C26, C27, C30: 0.1uF; 0402
CONN1, CONN4, CONN5, CONN6, CONN7: 292303-1; STYLEA,RIGHTANGLE,THROUGH-HOLE
CONN2: 675031030; MINI_B
CONN3: PJ-058AH
D1: B520C
D2: PMEG4005ET; SOT23
D3: MMBZ5V6ALT1G; SOT23
F1: MINI-SMDC200F
FB3, FB4, FB5, FB6: BLM18EG221SN1D; C0603
L1, L2, L3, L4: DLP11SN900SL2; 0504
R2, R3, R4, R5, R7, R14, R15, R16: 0; R0402
U3: PQ1L333M2SP
U4, U5: MIC2026A-1YM; SO_08

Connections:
+3V3: C8.1, C9.1, U3.5 (DC_OUTPUT(VO)); also elsewhere on the board
GND: BR1.1, BR2.1, BR3.1, BR4.1, C1.- (2), C7.2, C8.2, C9.2, C10.2, C18.2, C19.2, C20.- (2), C21.2, C22.2, C23.- (2), C24.2, C25.- (2), C26.2, C27.2, C28.2, C29.- (2), C30.2, CONN1.GND, CONN1.GND1 (GND), CONN1.GND2 (GND), CONN2.GND, CONN2.GND1 (GND), CONN2.GND2 (GND), CONN2.GND3 (GND), CONN2.GND4 (GND), CONN3.2, CONN3.3, CONN4.GND, CONN4.GND1 (GND), CONN4.GND2 (GND), CONN5.GND, CONN5.GND1 (GND), CONN5.GND2 (GND), CONN6.GND, CONN6.GND1 (GND), CONN6.GND2 (GND), CONN7.GND, CONN7.GND1 (GND), CONN7.GND2 (GND), D3.3, U3.2 (GND), U3.P$3 (GND), U4.6 (GND), U5.6 (GND); also elsewhere on the board
unnamed: C19.1, CONN5.VBUS, FB4.1
unnamed: BR2.2, CONN5.SIG2 (D+), L2.2, R14.1
unnamed: CONN3.1, D1.P$1 (1)
unnamed: C10.1, U3.1 (NOISE_REDUCTION(NR))
unnamed: C18.1, CONN4.VBUS, FB3.1
unnamed: BR1.2, CONN4.SIG2 (D+), L1.2, R7.1
unnamed: CONN1.VBUS, F1.2
unnamed: C24.1, CONN6.VBUS, FB5.1
unnamed: BR3.2, CONN6.SIG2 (D+), L3.2, R15.1
unnamed: C28.1, CONN7.VBUS, FB6.1
unnamed: BR4.2, CONN7.SIG2 (D+), L4.2, R16.1
NC1: CONN1.SIG2 (D+)
NC2: CONN1.SIG1 (D-)
NC3: CONN2.ID
OCS_N1: U4.2 (FLGA); also elsewhere on the board
OCS_N2: U4.3 (FLGB); also elsewhere on the board
OCS_N3: U5.2 (FLGA); also elsewhere on the board
OCS_N4: U5.3 (FLGB); also elsewhere on the board
PRTPWR1: U4.1 (ENA); also elsewhere on the board
PRTPWR2: U4.4 (ENB); also elsewhere on the board
PRTPWR3: U5.1 (ENA); also elsewhere on the board
PRTPWR4: U5.4 (ENB); also elsewhere on the board
PWR_IC_CN1_VBUS: BR1.3, C23.+ (1), C27.1, FB3.2, U4.8 (OUTA)
PWR_IC_CN2_VBUS: BR2.3, C20.+ (1), C21.1, FB4.2, U4.5 (OUTB)
PWR_IC_CN3_VBUS: BR3.3, C25.+ (1), C26.1, FB5.2, U5.8 (OUTA)
PWR_IC_CN4_VBUS: BR4.3, C29.+ (1), C30.1, FB6.2, U5.5 (OUTB)
USBDN1_U2U_USBCON_N: L1.4, R5.1; also elsewhere on the board
USBDN1_U2U_USBCON_P: L1.1, R7.2; also elsewhere on the board
USBDN1_U2U_USBCON_P2: BR4.4, CONN7.SIG1 (D-), L4.3, R2.2
USBDN1_U2U_USBCON_P3: BR3.4, CONN6.SIG1 (D-), L3.3, R3.2
USBDN1_U2U_USBCON_P4: BR2.4, CONN5.SIG1 (D-), L2.3, R4.2
USBDN1_U2U_USBCON_P5: BR1.4, CONN4.SIG1 (D-), L1.3, R5.2
USBDN2_U2U_USBCON_N: L2.4, R4.1; also elsewhere on the board
USBDN2_U2U_USBCON_P: L2.1, R14.2; also elsewhere on the board
USBDN3_U2U_USBCON_N: L3.4, R3.1; also elsewhere on the board
USBDN3_U2U_USBCON_P: L3.1, R15.2; also elsewhere on the board
USBDN4_U2U_USBCON_N: L4.4, R2.1; also elsewhere on the board
USBDN4_U2U_USBCON_P: L4.1, R16.2; also elsewhere on the board
USBUP_USBCON_U2U_N: CONN2.D-; also elsewhere on the board
USBUP_USBCON_U2U_P: CONN2.D+; also elsewhere on the board
VBUS_UP: C22.1, CONN2.VBUS, D2.1; also elsewhere on the board
VCC: C1.+ (1), C7.1, D1.P$2 (3), D2.3, D3.1, D3.2, F1.1, U3.3 (ON/OFF_CONTROL), U3.4 (DC_INPUT(VIN)), U4.7 (IN), U5.7 (IN)

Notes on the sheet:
2/3
V1.0
Lorence Balucos
10LA.org
Raspiado
4PxU_RPiSB
HUB Ports

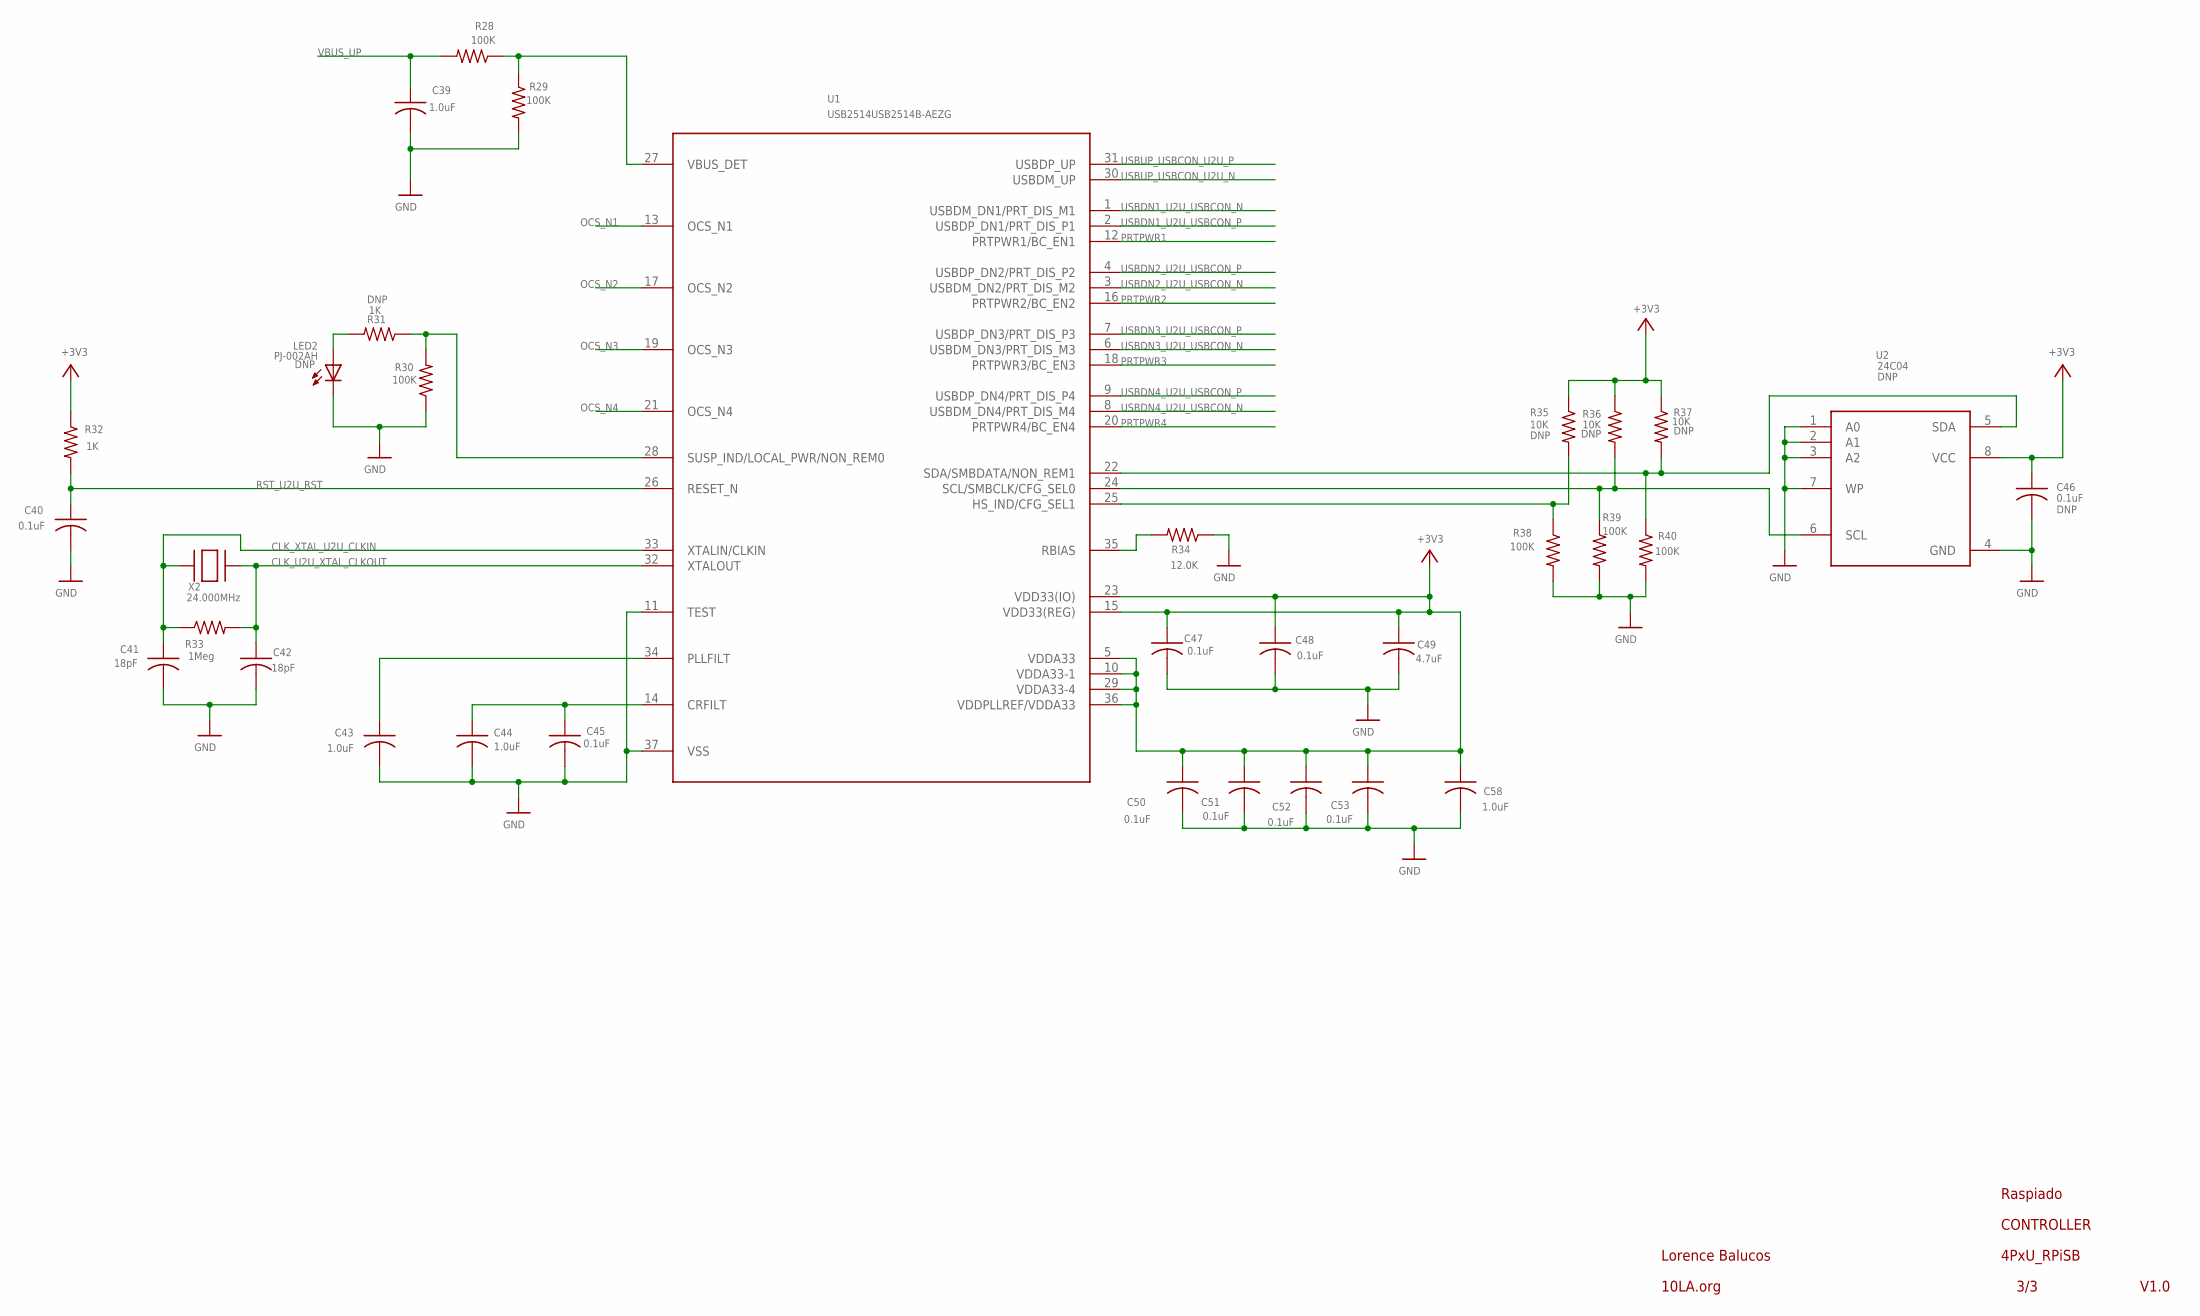
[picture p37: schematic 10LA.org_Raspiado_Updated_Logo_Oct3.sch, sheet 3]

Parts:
C39, C58: 1.0uF; C0603
C40, C45, C46, C47, C48, C50, C51, C52, C53: 0.1uF; 0402
C41, C42: 18pF; 0402
C43, C44: 1.0uF; 0402
C49: 4.7uF; C0603
LED2: PJ-002AH; 0603
R28, R29, R30, R38, R39, R40: 100K; R0603
R31, R32: 1K; R0603
R33: 1Meg; R0603
R34: 12.0K; R0603
R35, R36, R37: 10K; R0603
U1: USB2514USB2514B-AEZG; QFN36
U2: 24C04; SO-8
X2: 24.000MHz; HC-49SMT

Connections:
+3V3: C46.1, C47.1, C48.1, C49.1, C50.1, C51.1, C52.1, C53.1, C58.1, R32.1, R35.1, R36.1, R37.1, U1.5 (VDDA33), U1.10 (VDDA33-1), U1.15 (VDD33(REG)), U1.23 (VDD33(IO)), U1.29 (VDDA33-4), U1.36 (VDDPLLREF/VDDA33), U2.8 (VCC); also elsewhere on the board
CLK_U2U_XTAL_CLKOUT: C42.1, R33.2, U1.32 (XTALOUT), X2.2
CLK_XTAL_U2U_CLKIN: C41.1, R33.1, U1.33 (XTALIN/CLKIN), X2.1
CRFILT: C44.1, C45.1, U1.14 (CRFILT)
GND: C39.2, C40.2, C41.2, C42.2, C43.2, C44.2, C45.2, C46.2, C47.2, C48.2, C49.2, C50.2, C51.2, C52.2, C53.2, C58.2, LED2.C, R29.2, R30.1, R34.1, R38.2, R39.2, R40.2, U1.11 (TEST), U1.37 (VSS), U2.1 (A0), U2.2 (A1), U2.3 (A2), U2.4 (GND), U2.7 (WP); also elsewhere on the board
unnamed: LED2.A, R31.2
OCS_N1: U1.13 (OCS_N1); also elsewhere on the board
OCS_N2: U1.17 (OCS_N2); also elsewhere on the board
OCS_N3: U1.19 (OCS_N3); also elsewhere on the board
OCS_N4: U1.21 (OCS_N4); also elsewhere on the board
PLLFILT: C43.1, U1.34 (PLLFILT)
PRTPWR1: U1.12 (PRTPWR1/BC_EN1); also elsewhere on the board
PRTPWR2: U1.16 (PRTPWR2/BC_EN2); also elsewhere on the board
PRTPWR3: U1.18 (PRTPWR3/BC_EN3); also elsewhere on the board
PRTPWR4: U1.20 (PRTPWR4/BC_EN4); also elsewhere on the board
RBIAS: R34.2, U1.35 (RBIAS)
REM0: R30.2, R31.1, U1.28 (SUSP_IND/LOCAL_PWR/NON_REM0)
REM1: R37.2, R40.1, U1.22 (SDA/SMBDATA/NON_REM1), U2.5 (SDA)
RST_U2U_RST: C40.1, R32.2, U1.26 (RESET_N)
SCL: R36.2, R39.1, U1.24 (SCL/SMBCLK/CFG_SEL0), U2.6 (SCL)
SEL1: R35.2, R38.1, U1.25 (HS_IND/CFG_SEL1)
USBDN1_U2U_USBCON_N: U1.1 (USBDM_DN1/PRT_DIS_M1); also elsewhere on the board
USBDN1_U2U_USBCON_P: U1.2 (USBDP_DN1/PRT_DIS_P1); also elsewhere on the board
USBDN2_U2U_USBCON_N: U1.3 (USBDM_DN2/PRT_DIS_M2); also elsewhere on the board
USBDN2_U2U_USBCON_P: U1.4 (USBDP_DN2/PRT_DIS_P2); also elsewhere on the board
USBDN3_U2U_USBCON_N: U1.6 (USBDM_DN3/PRT_DIS_M3); also elsewhere on the board
USBDN3_U2U_USBCON_P: U1.7 (USBDP_DN3/PRT_DIS_P3); also elsewhere on the board
USBDN4_U2U_USBCON_N: U1.8 (USBDM_DN4/PRT_DIS_M4); also elsewhere on the board
USBDN4_U2U_USBCON_P: U1.9 (USBDP_DN4/PRT_DIS_P4); also elsewhere on the board
USBUP_USBCON_U2U_N: U1.30 (USBDM_UP); also elsewhere on the board
USBUP_USBCON_U2U_P: U1.31 (USBDP_UP); also elsewhere on the board
VBUS_UP: C39.1, R28.2; also elsewhere on the board
VBUS_UPSTREAM: R28.1, R29.1, U1.27 (VBUS_DET)

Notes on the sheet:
4PxU_RPiSB
3/3
V1.0
Lorence Balucos
10LA.org
Raspiado
CONTROLLER

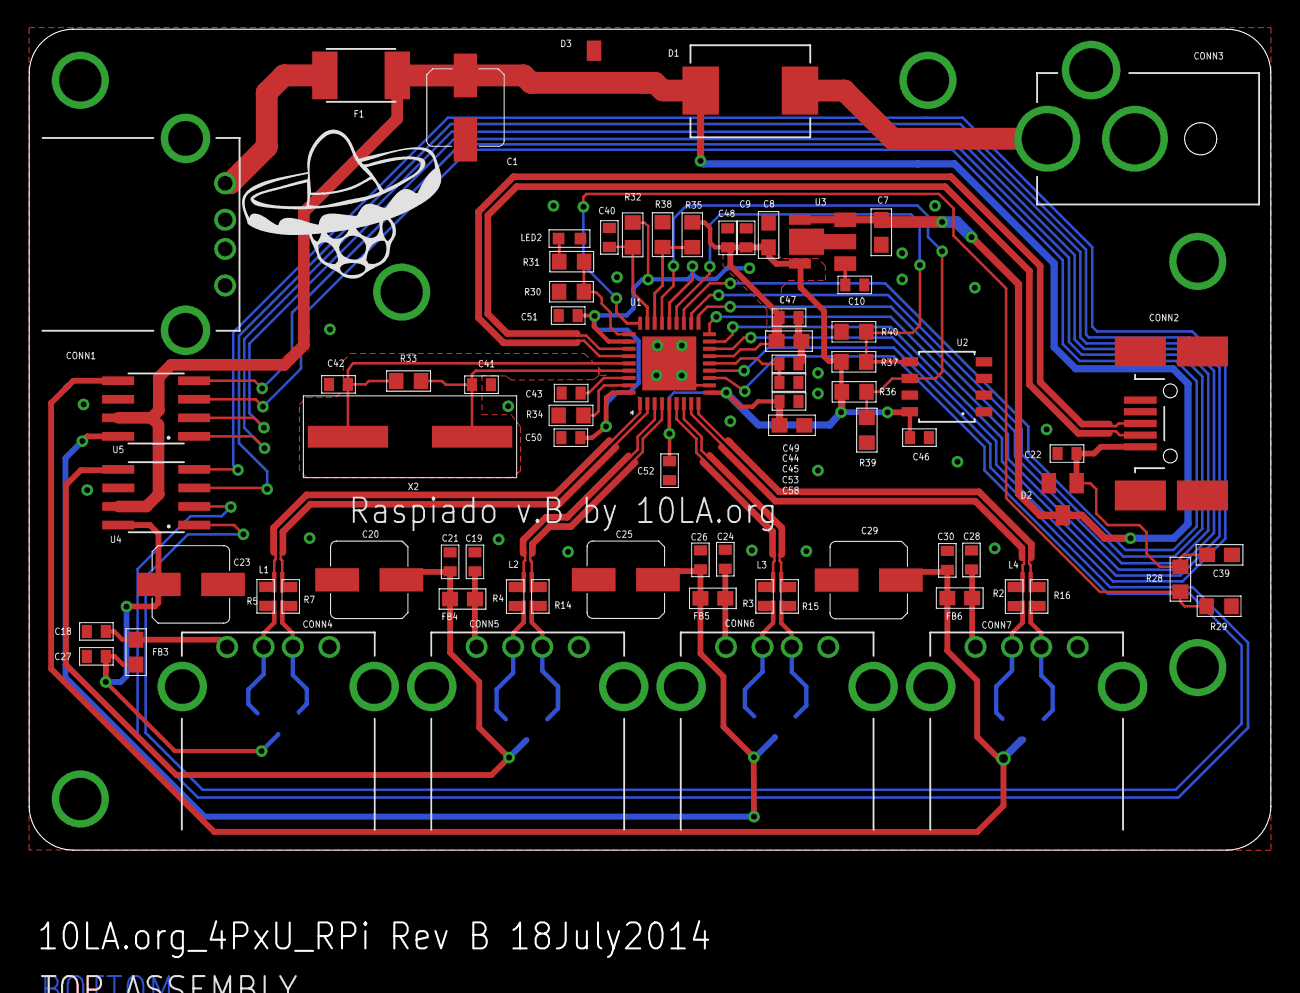
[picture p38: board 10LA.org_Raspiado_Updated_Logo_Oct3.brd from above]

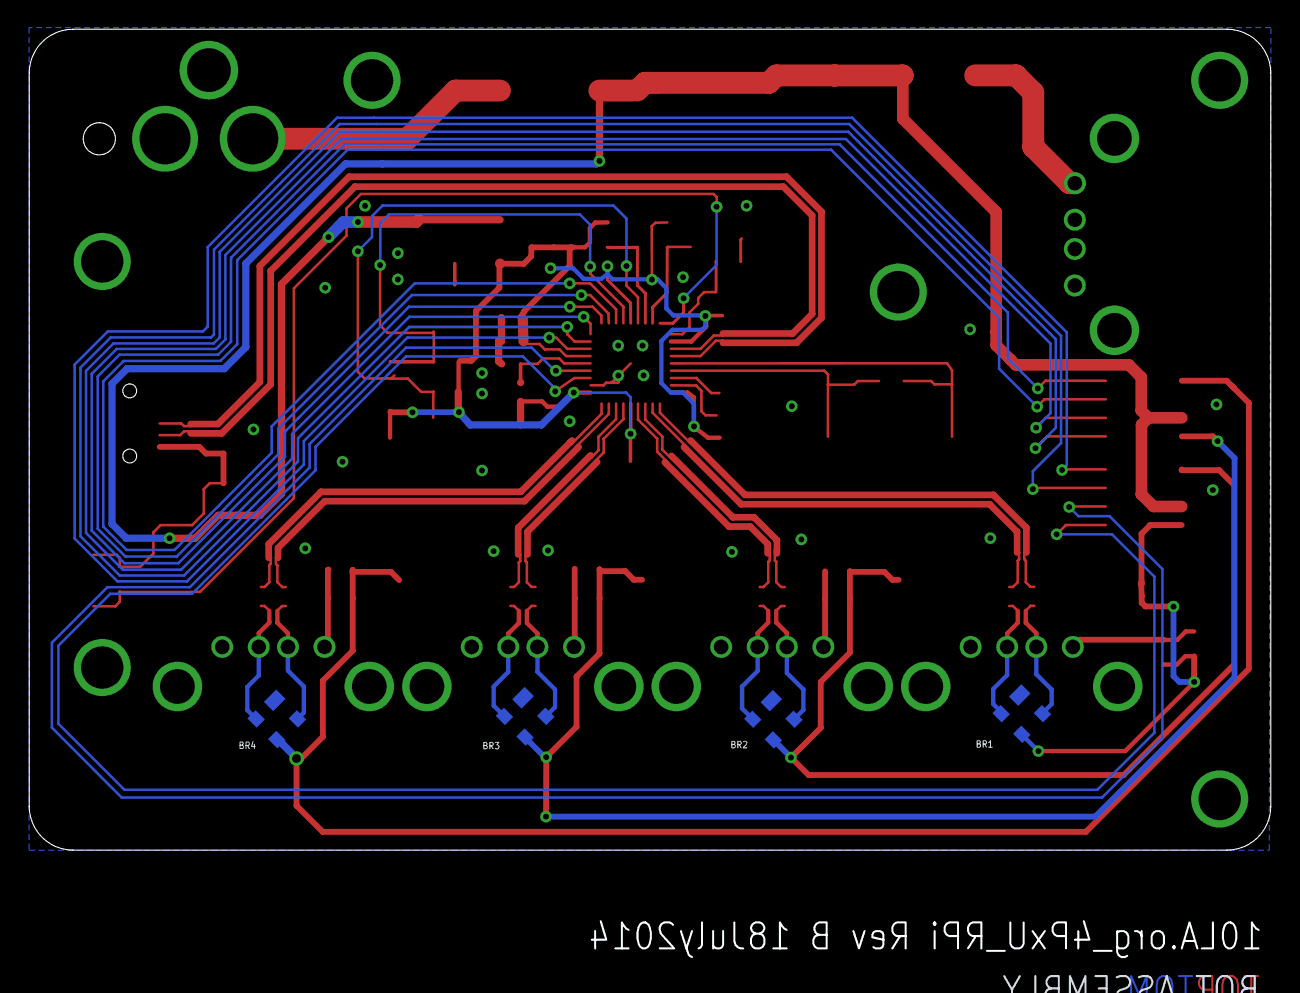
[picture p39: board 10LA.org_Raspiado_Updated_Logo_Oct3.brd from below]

Board: 2 copper layers, 85.0 x 56.2 mm, 86 parts (4 on the bottom side), 53 nets.

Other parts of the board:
U$1: FRAME

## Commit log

2018-03-13 ADD more media files
    [BOM_Raspiado_V1P4_crossreferences.xlsx, RaspiHub.brd, RaspiHub.sch]
2018-03-13 RENAME design file folder
    [10LA.org_4PxU_RPi.brd, 10LA.org_4PxU_RPi.sch, 10LA.org_Raspiado_Updated_Logo_Oct3.brd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]
2018-03-16 ADD pics and text to README for PCB design files
